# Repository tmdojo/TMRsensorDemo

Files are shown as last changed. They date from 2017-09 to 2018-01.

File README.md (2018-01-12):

# TMR Sensor Demo

This repo contains demo board and code for TDK TMR Angle Sensor
https://product.tdk.com/info/en/products/sensor/angle/tmr-angle/index.html

Important Note!
In v1.1 27-Apr-2017 board, Pin#1 ADDR of ADC1x15 is routed to GPIO #11 of Feather. Set this pin to LOW or HIGH for proper operation.
TMRsensorDemo.ino has been updated to accomodate this.

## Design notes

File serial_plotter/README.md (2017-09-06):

# serial_plotter

Python code to

1. Read data from serial port or MQTT subscription
2. Save data to file
3. Plot data in real time

This tool works nice with Arduino and the like.

## Dependancies

* Python 3.5
* PyQt4
* pyqtgraph
* numpy
* pySerial
* paho

## Environment setup

It is recommended to setup a new anaconda environment and install dependancies. Take special note that conda installs PyQt5 by default and you need to downgrade it to PyQt4.

conda create -n serialplotter python=3.5 anaconda
source activate serialplotter
conda install pyqt=4.11.4
conda install pyqtgraph pySerial
pip install paho-mqtt

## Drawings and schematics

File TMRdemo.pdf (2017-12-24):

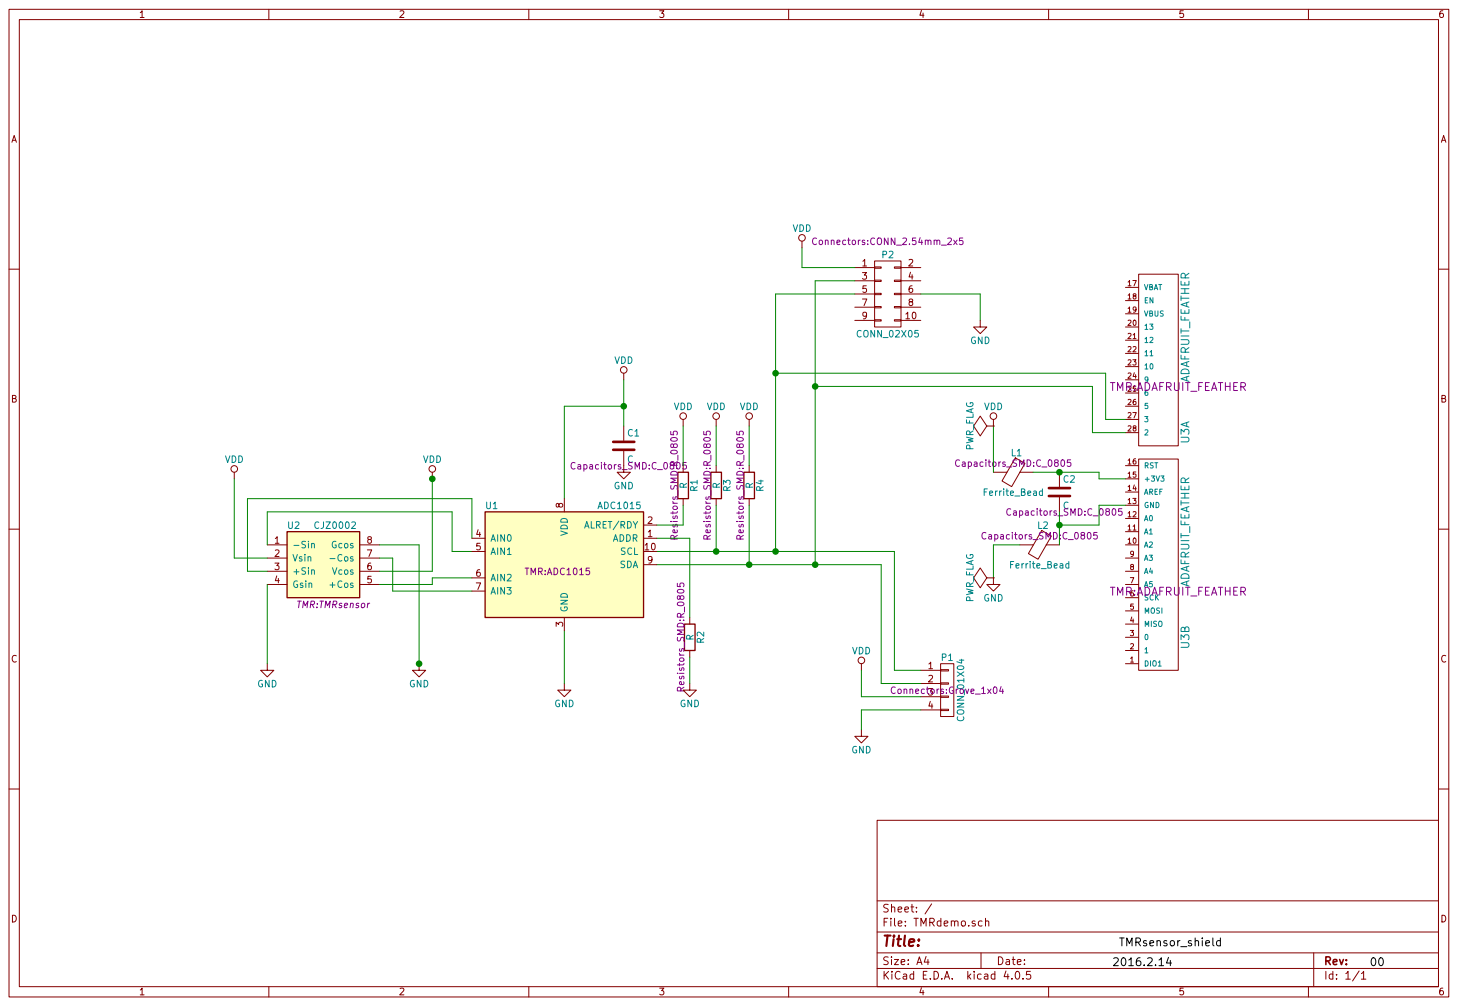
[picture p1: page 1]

Id: 1/1 Title: File: TMRdemo.sch Sheet: / GND

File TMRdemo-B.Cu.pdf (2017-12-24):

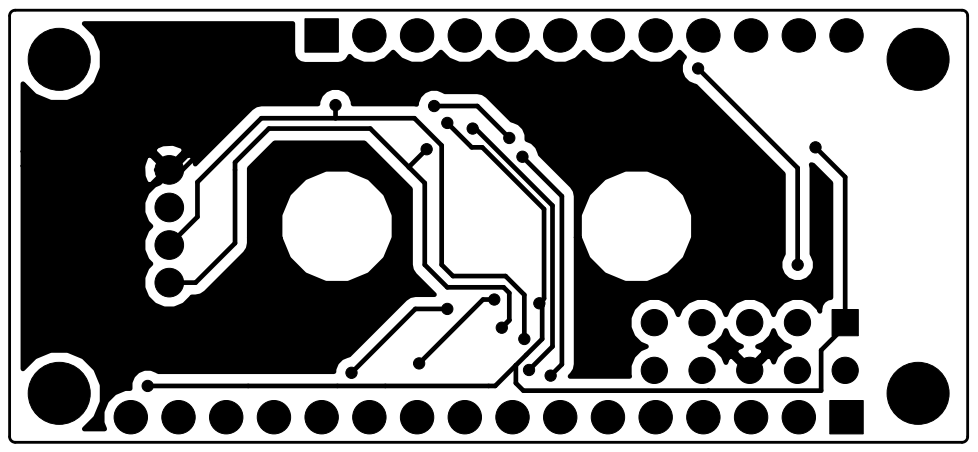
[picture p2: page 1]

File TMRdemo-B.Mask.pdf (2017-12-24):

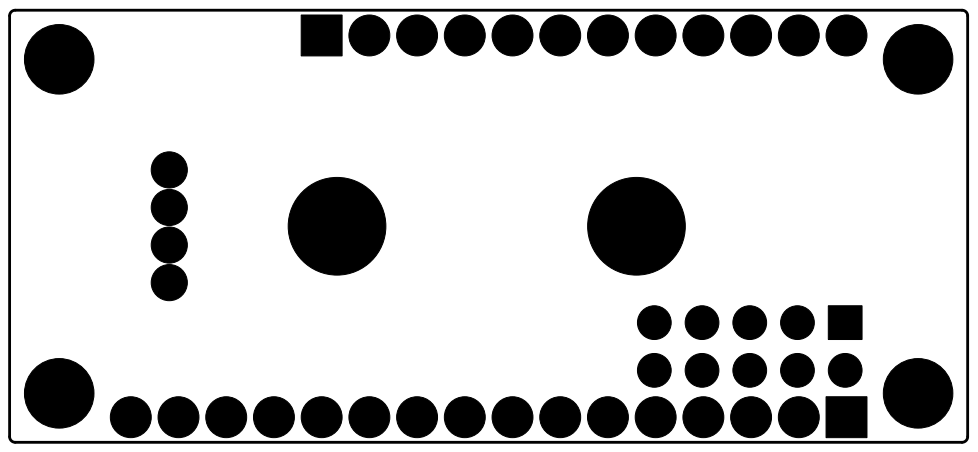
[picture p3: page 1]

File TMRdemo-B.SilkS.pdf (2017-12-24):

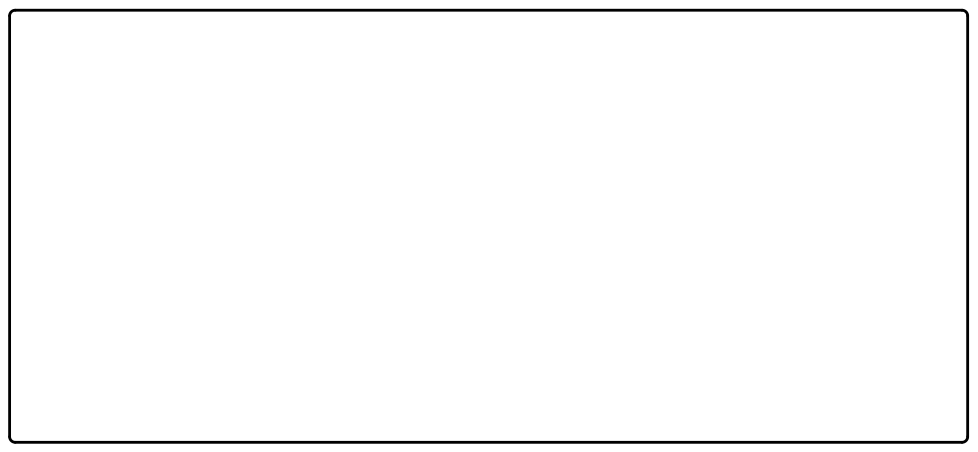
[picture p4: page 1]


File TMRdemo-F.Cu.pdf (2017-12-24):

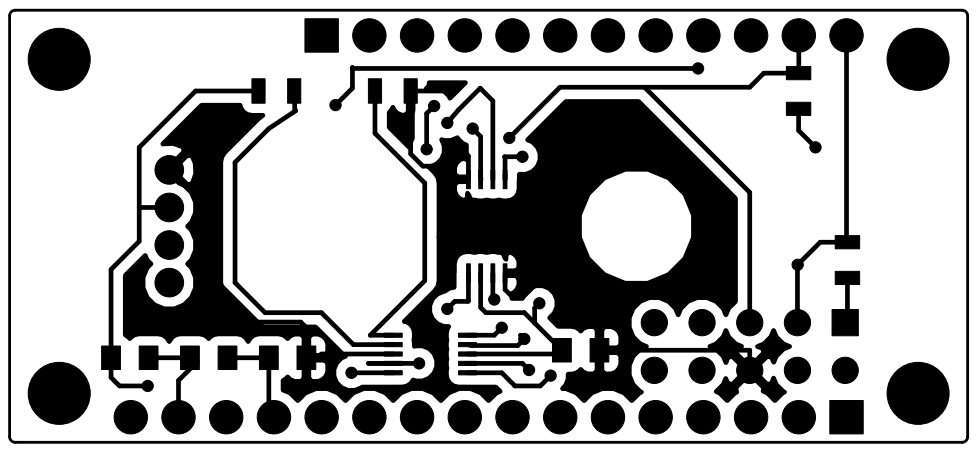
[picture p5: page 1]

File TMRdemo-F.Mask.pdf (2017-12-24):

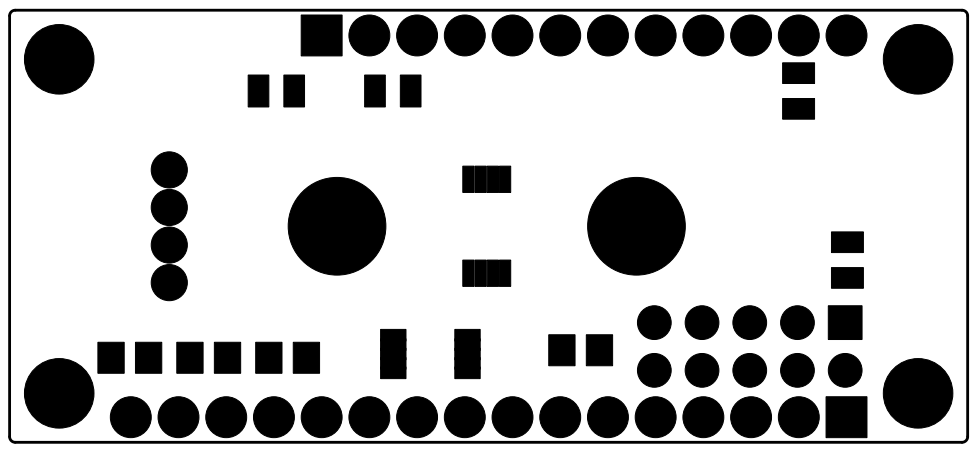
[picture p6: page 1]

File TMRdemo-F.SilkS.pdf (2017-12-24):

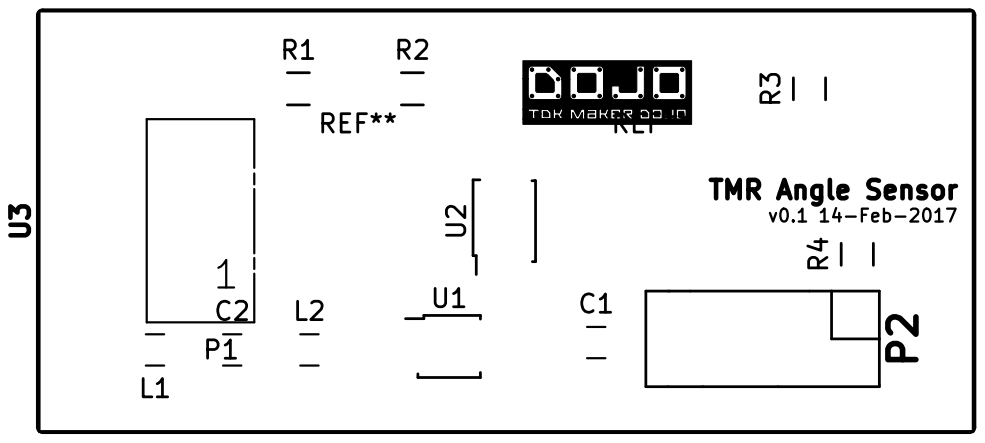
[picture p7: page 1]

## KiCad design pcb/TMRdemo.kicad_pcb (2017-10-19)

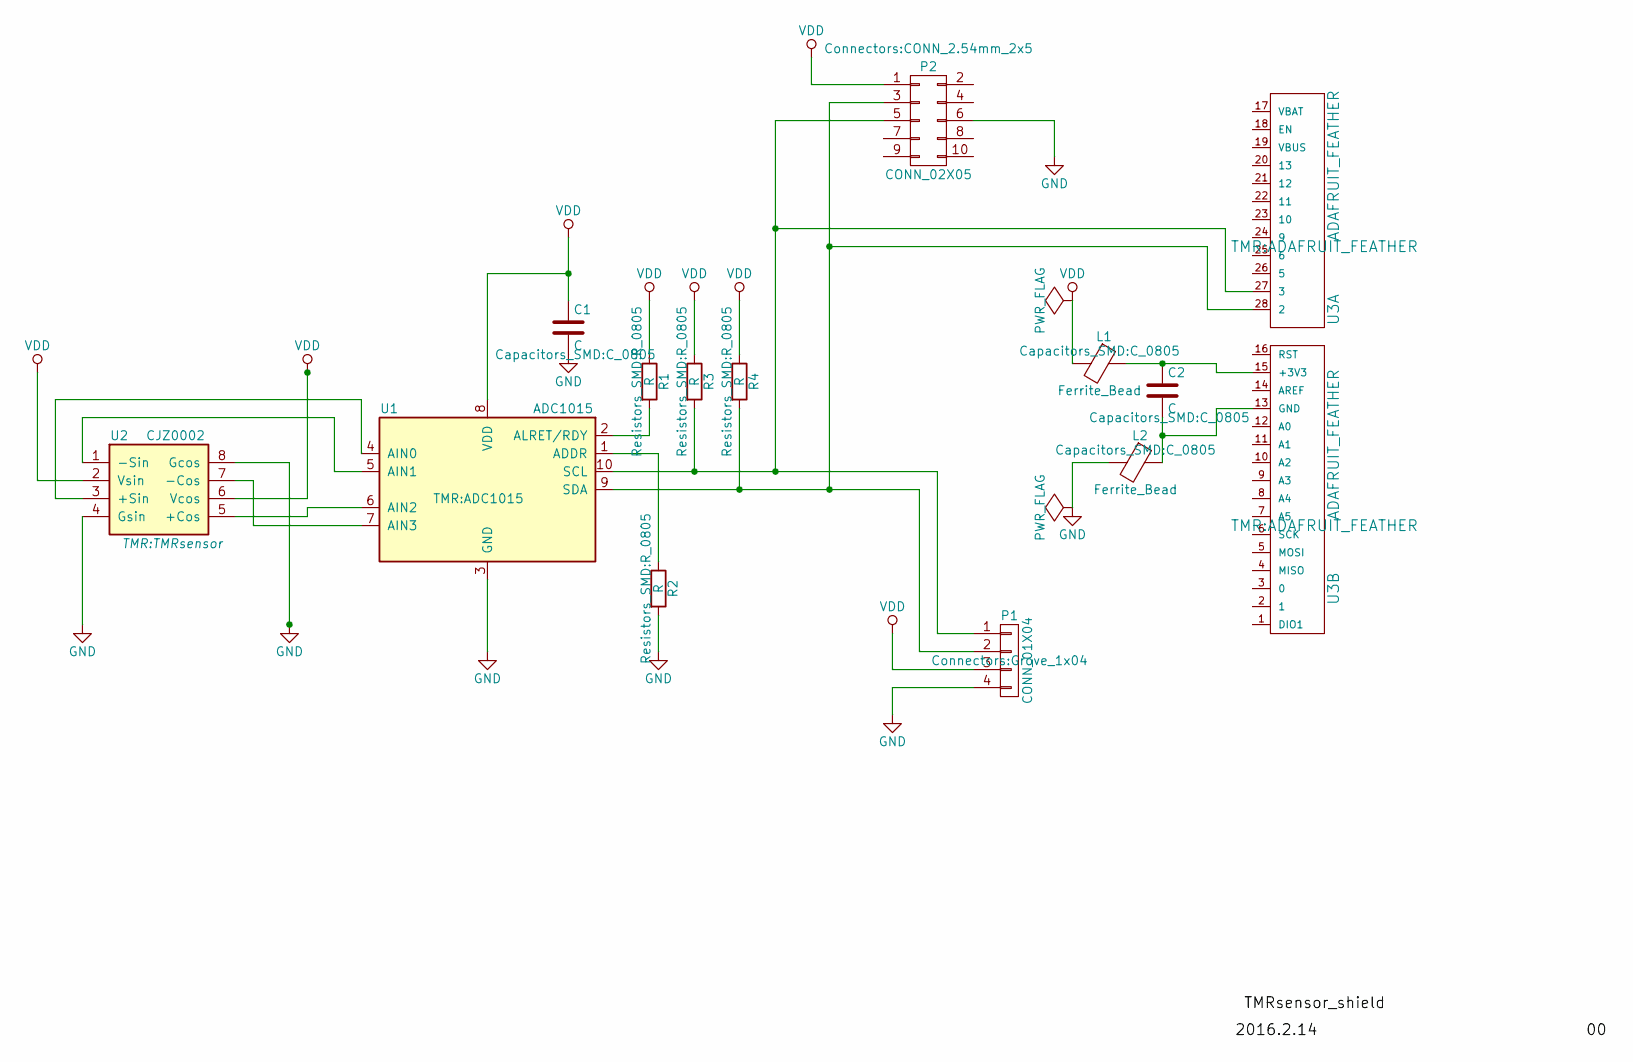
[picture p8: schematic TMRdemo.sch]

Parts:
C1, C2: C; C_0805
L1, L2: Ferrite_Bead; C_0805
P1: CONN_01X04; Grove_1x04
P2: CONN_02X05; CONN_2.54mm_2x5
R1, R2, R3, R4: R; R_0805
U1: ADC1015
U2: CJZ0002; TMRsensor
U3: ADAFRUIT_FEATHER

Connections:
GND: C1.2, L2.2, P1.4, P2.6, R2.2, U1.3 (GND), U2.4 (Gsin), U2.8 (Gcos)
unnamed: C2.1, L1.1, U3.15 (+3V3)
unnamed: C2.2, L2.1, U3.13 (GND)
unnamed: P1.1, P2.5, R3.2, U1.10 (SCL), U3.27 (3)
unnamed: P1.2, P2.3, R4.2, U1.9 (SDA), U3.28 (2)
unnamed: R1.2, U1.2 (ALRET/RDY)
unnamed: R2.1, U1.1 (ADDR)
unnamed: U1.4 (AIN0), U2.3 (+Sin)
unnamed: U1.5 (AIN1), U2.1 (-Sin)
unnamed: U1.6 (AIN2), U2.5 (+Cos)
unnamed: U1.7 (AIN3), U2.7 (-Cos)
VDD: C1.1, L1.2, P1.3, P2.1, R1.1, R3.1, R4.1, U1.8 (VDD), U2.2 (Vsin), U2.6 (Vcos)

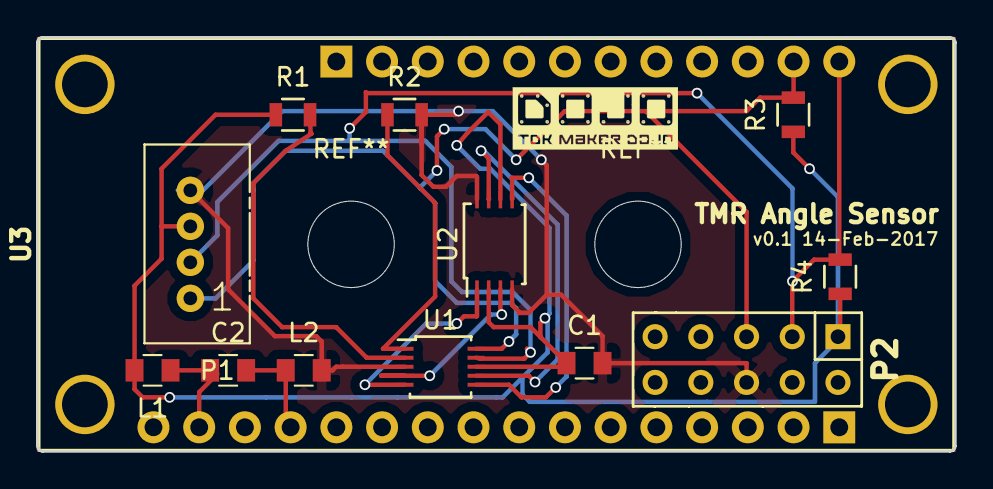
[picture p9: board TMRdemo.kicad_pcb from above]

Board: 2 copper layers, 51.0 x 23.0 mm, 13 parts (0 on the bottom side), 12 nets.

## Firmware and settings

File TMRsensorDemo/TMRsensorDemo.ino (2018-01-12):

/*
TMR Angle Sensor example code

This code demonstrates how to read data from ADS1015 ADC on the TMR Sensor demonstration board.

You would need to install Adafruit_ADS1X15 library
v1.2.1 by soligen2010
https://github.com/soligen2010/Adafruit_ADS1X15

Other libraries used:
https://github.com/adafruit/Adafruit-GFX-Library
https://github.com/adafruit/Adafruit_SSD1306
https://github.com/adafruit/Adafruit_NeoPixel

This example uses an OLED dispaly and a neopixel to show data.
Display: 128X64 0.96 inch OLED Display such as
https://www.aliexpress.com/store/product/1Pcs-blue-128X64-OLED-LCD-LED-Display-Module-0-96-I2C-IIC-SPI-Serial-new-original/535576_32523645959.html

Author: Shunya Sato

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
THE SOFTWARE IS PROVIDED "AS IS", WITHOUT WARRANTY OF ANY KIND, EXPRESS OR
IMPLIED, INCLUDING BUT NOT LIMITED TO THE WARRANTIES OF MERCHANTABILITY,
FITNESS FOR A PARTICULAR PURPOSE AND NONINFRINGEMENT. IN NO EVENT SHALL THE
AUTHORS OR COPYRIGHT HOLDERS BE LIABLE FOR ANY CLAIM, DAMAGES OR OTHER
LIABILITY, WHETHER IN AN ACTION OF CONTRACT, TORT OR OTHERWISE, ARISING FROM,
OUT OF OR IN CONNECTION WITH THE SOFTWARE OR THE USE OR OTHER DEALINGS IN
THE SOFTWARE.
*/

#include <Wire.h>
#include <math.h>
#include <Adafruit_ADS1015.h>
#include <Adafruit_GFX.h>
#include <Adafruit_SSD1306.h>
#include <Adafruit_NeoPixel.h>

Adafruit_ADS1115 ads;  /* Use this for the 16-bit version */
//Adafruit_ADS1015 ads;     /* Use this for the 12-bit version */

// cheap OLED display
#define OLED_RESET -1
Adafruit_SSD1306 display(OLED_RESET);

#define PIN 2 // Neopixel pin
Adafruit_NeoPixel strip = Adafruit_NeoPixel(1, PIN, NEO_GRB + NEO_KHZ800);

float multiplier; // convert ADC reading to mV
const double rad2deg_multiplier = 180 / M_PI;
float rho_max = 1200; // initial maximum of sqrt(sq(sin_mv) + sq(cos_mv))

void setup(void)
{
  Serial.begin(115200);
  Serial.println("Hello!");

  Serial.println("Getting differential reading from AIN0 (P) and AIN1 (N)");
  Serial.println("ADC Range: +/- 6.144V (1 bit = 3mV/ADS1015, 0.1875mV/ADS1115)");

  // set Pin#1 ADDR of ADC1x15 LOW or HIGH for prpoer operation
  pinMode(11, OUTPUT);
  digitalWrite(11, LOW);

  // The ADC input range (or gain) can be changed via the following
  // functions, but be careful never to exceed VDD +0.3V max, or to
  // exceed the upper and lower limits if you adjust the input range!
  // Setting these values incorrectly may destroy your ADC!
  //                                                                ADS1015  ADS1115
  //                                                                -------  -------
  ads.setGain(GAIN_TWOTHIRDS);  // 2/3x gain +/- 6.144V  1 bit = 3mV      0.1875mV (default)
  // ads.setGain(GAIN_ONE);        // 1x gain   +/- 4.096V  1 bit = 2mV      0.125mV
  // ads.setGain(GAIN_TWO);        // 2x gain   +/- 2.048V  1 bit = 1mV      0.0625mV
  // ads.setGain(GAIN_FOUR);       // 4x gain   +/- 1.024V  1 bit = 0.5mV    0.03125mV
  // ads.setGain(GAIN_EIGHT);      // 8x gain   +/- 0.512V  1 bit = 0.25mV   0.015625mV
  // ads.setGain(GAIN_SIXTEEN);    // 16x gain  +/- 0.256V  1 bit = 0.125mV  0.0078125mV

  ads.begin();

  multiplier = ads.voltsPerBit()*1000.0F;    /* Sets the millivolts per bit */

  /* Use this to set data rate for the 12-bit version (optional)*/
  //ads.setSPS(ADS1015_DR_3300SPS);      // for ADS1015 fastest samples per second is 3300 (default is 1600)

  /* Use this to set data rate for the 16-bit version (optional)*/
  ads.setSPS(ADS1115_DR_860SPS);      // for ADS1115 fastest samples per second is 860 (default is 128)

  display.begin(SSD1306_SWITCHCAPVCC, 0x3C);  // initialize with the I2C addr 0x3D (for the 128x64)
  display.clearDisplay();
  display.setTextSize(2);
  display.setTextColor(WHITE);
  display.setCursor(0,0);
  display.println("TMR Sensor");
  display.display();

  strip.begin();
  strip.show(); // Initialize all pixels to 'off'

}

void loop(void)
{
  int16_t results0_1, results2_3;
  results0_1 = ads.readADC_Differential_0_1();
  results2_3 = ads.readADC_Differential_2_3();
  float sin_mv = results0_1 * multiplier;
  float cos_mv = results2_3 * multiplier;

  // Note that this is a simple way to derive angle with limited accuracy
  // TDK has developed elavorated correction algorithm to achieve higher accuracy.
  // Please contact TDK for details.
  double angle_rad = atan2(sin_mv, cos_mv);
  double angle = angle_rad * rad2deg_multiplier; // convert radian to degree
  float rho = sqrt(sq(sin_mv)+sq(cos_mv));
  if (rho > rho_max) rho_max = rho;
  float rho_ratio = rho / rho_max;

  Serial.print(sin_mv);
  Serial.print(",");
  Serial.print(cos_mv);
  Serial.print(",");
  Serial.println(angle);

  updateDisplay(angle, angle_rad, rho_ratio);
  updateNeopixel(angle);

  delay(100);
}

void updateDisplay(double angle, double angle_rad, float rho_ratio){
  // OLED display of size: 128x64
  display.clearDisplay();
  display.setTextSize(2);
  display.setTextColor(WHITE);
  display.setCursor(0,0);
  display.println("TMR Sensor");
  display.setCursor(0,20);
  display.println("Angle: ");
  display.setCursor(0,40);
  display.println(angle);

  // draw compass
  int r = 20;
  // draw outter circle
  display.drawCircle(128-r-1, 64-r-1, r, WHITE);
  // draw angle line
  display.drawLine(128-r-1, 64-r-1, 128-r-1+r*cos(angle_rad), 64-r-1-r*sin(angle_rad), WHITE);
  // draw Lissajous
  display.drawCircle(128-r-1+r*rho_ratio*cos(angle_rad), 64-r-1-r*rho_ratio*sin(angle_rad), 3, WHITE);
  display.display();
}

void updateNeopixel(double angle){
  int pos = map(angle, -180, 180, 0, 255);
  pos = constrain(pos, 0, 255);
  strip.setPixelColor(0, Wheel(pos));
  strip.show();
}

// Input a value 0 to 255 to get a color value.
// The colours are a transition r - g - b - back to r.
uint32_t Wheel(byte WheelPos) {
  WheelPos = 255 - WheelPos;
  if(WheelPos < 85) {
   return strip.Color(255 - WheelPos * 3, 0, WheelPos * 3);
  } else if(WheelPos < 170) {
    WheelPos -= 85;
   return strip.Color(0, WheelPos * 3, 255 - WheelPos * 3);
  } else {
   WheelPos -= 170;
   return strip.Color(WheelPos * 3, 255 - WheelPos * 3, 0);
  }
}

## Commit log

2017-10-19 Add KiCad PCB
    [TMRdemo.kicad_pcb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]
2018-01-12 Amend README and .ino for v1.1 board. Board data is not updated.
